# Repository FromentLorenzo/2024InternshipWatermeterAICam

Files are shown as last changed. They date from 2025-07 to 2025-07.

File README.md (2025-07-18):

# Project: Water Meter Reading with Camera-based Index Recognition

## Table of Contents

1. [Description of the Project](#1-description-of-the-project)
   - [Equipment Used](#equipment-used)
   - [Software Used](#software-used)
2. [What is Done](#2-what-is-done)
   - [ESP32-CAM Code](#about-the-esp32-cam-code)
   - [Convolutional Neural Network](#about-the-cnn)
   - [Camera Support](#about-the-support-for-the-esp32-cam)
   - [Grafana](#about-the-grafana)
3. [How to Use/Launch the Project](#3-how-to-uselaunch-the-project)
   - [Arduino Code](#arduino-code)
   - [Convolutional Neural Network Code](#convolutional-neural-network-code)
   - [Docker Container](#docker-container)
4. [What is Missing (Bugs)](#4-what-is-missing-bugs)

##
# 1. Description of the project:

The aim of this project was to enable automatic reading of water meter readings, enabling monitoring and automatic triggering of alerts in the event of abnormal consumption. 

## Equipment used
For this project, we used an ESP32-CAM  


## Software used

In order to code on the ESP32-CAM we used the software called Arduino IDE

 
We also used Google collab in order to train a CNN model able to predict digits.


# 2. What is done
## About the ESP32-CAM code

We developped a code able to take a picture with the flash LED of the ESP32-CAM, save it on the micro SD card, crop the original picture into 5 pictures (the 5 digits of the water meter) and save them on the micro SD. 

Then, we take these 5 pictures and apply the necessary preprocessing on them.

## About the CNN

We built our own dataset composed of digital digits but also half-half digits to solve the water meter display problem.
You can have access to the dataset in the ZIP file called "digits"

alt text for screen readers digit 1 from dataset
alt text for screen readers digit 1 merged from dataset

In our notebook "CNN_MODEL" you will find the differents step to train the model with comments.
Here are the main steps:
- Import necessary libraries
- Load the dataset
- Apply a full preprocessing to each pictures of the dataset
- Build a model with complex layers
- Train this model with the datasets' pictures
- Converting a Keras Model to a C++ Representation

With our dataset, preprocessing and model we are able to reach a 99% of accuracy. 

## About the support for the ESP32-CAM

We created a sort of support in order to protect the camera and make it motionless.

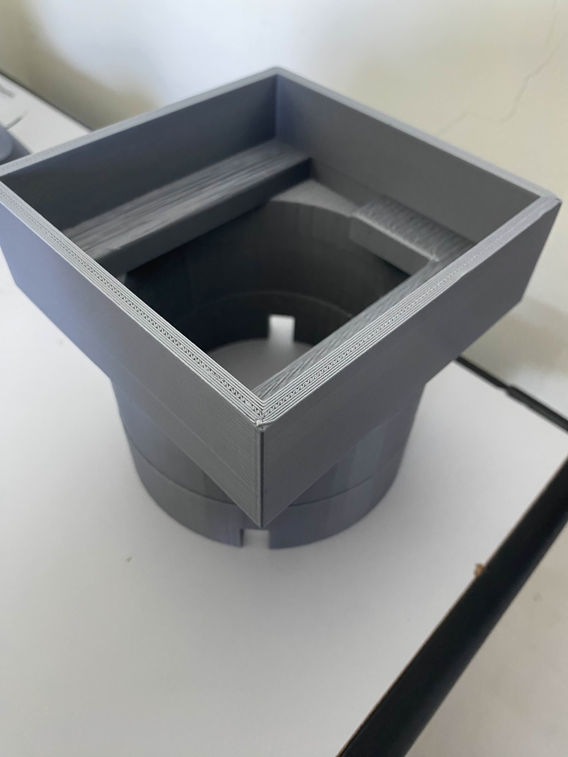
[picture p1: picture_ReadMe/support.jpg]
alt text for screen readers support for the camera


This support is made of 3 pieces in order to make it adjustable to have a better focus.

## About the Grafana

We developped a docker compose file composed of 3 services:
- Node-red, present for facilitate the connection between the LoRaWAN server and the database where values are stored 

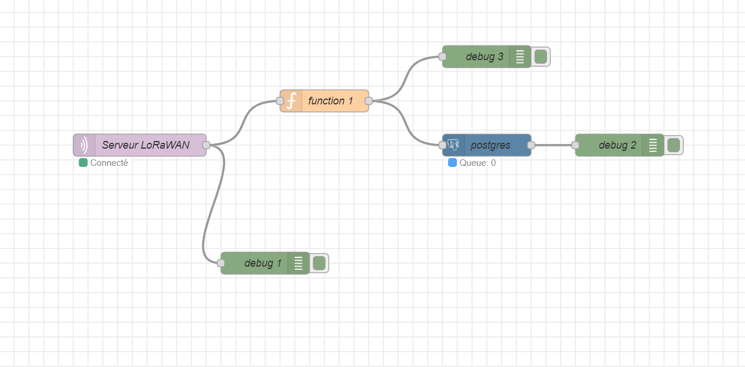
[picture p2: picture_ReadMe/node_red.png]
alt text for screen readers node-red page


- Postgres, which is the database used to store the values predicted and send by our ESP32-CAM
- Grafana, which is the service charged to get the values from the database and display them in order to keep track of consumption.

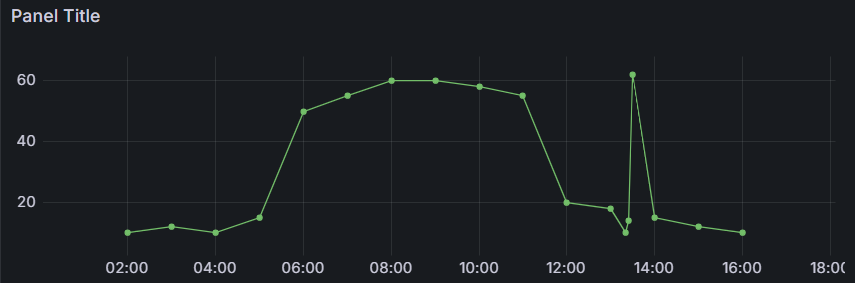
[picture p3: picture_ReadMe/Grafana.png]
alt text for screen readers Grafana page


# 3. How to use/launch the project

## Arduino code

First, lets set up the arduino IDE if you never used a ESP32-CAM.

Follow this tutorial to set up the Arduino IDE.
https://randomnerdtutorials.com/installing-esp32-arduino-ide-2-0/

After that, you can follow this tutorial to test if everything is working.
https://randomnerdtutorials.com/esp32-cam-video-streaming-face-recognition-arduino-ide/

After doing that, you can download the .ino file from the github project. Upload the code on the ESP32-CAM and open the Serial Monitor.
Here you will get an IP adress 

alt text for screen readers ip adress
Please visit this address in your browser and use the "Capture Image" button. This interface is provisional, designed to let you view the images captured by the ESP32-CAM without needing to remove the microSD card and connect it to your computer each time.
On this page, you can view the captured image along with the five preprocessed cropped images.

## Convolutional Neural Network code

If you want to take a look at the CNN code, you can download it from the github project. It is full of comments to help you understand how it is working. You also have to download the digits folder which is the dataset needed by the code to be able to train the model.
You can also use it to test the prediction on any pictures. (cell commented **"Manual Testing of the CNN Model"**)
The model has between 98 and 99% of accuracy and can easily predict digits even with average quality pictures.

## Docker container

In the github project, you can download the docker-compose file which is needed to launch the node-red, postgresSQL and grafana images.
Once downloaded, you have to type in a terminal the command: 
```
docker compose up -d --build
```

Once everything is launched, you can acces the node-red page at this adress: http://localhost:1880
You can access the Grafana page at this address:
http://localhost:3000/

The username/password are "**admin**"

# 4. What is missing (bugs)

In this project, some parts are missing in order to finish it.

1. **(BUG)** When we take a photo with the interface on the web server, the photo is correctly displayed wwith the cropped pictures. However, the pictures saved on the microSD are ALWAYS the same.

Here is the picture I take with the CAM

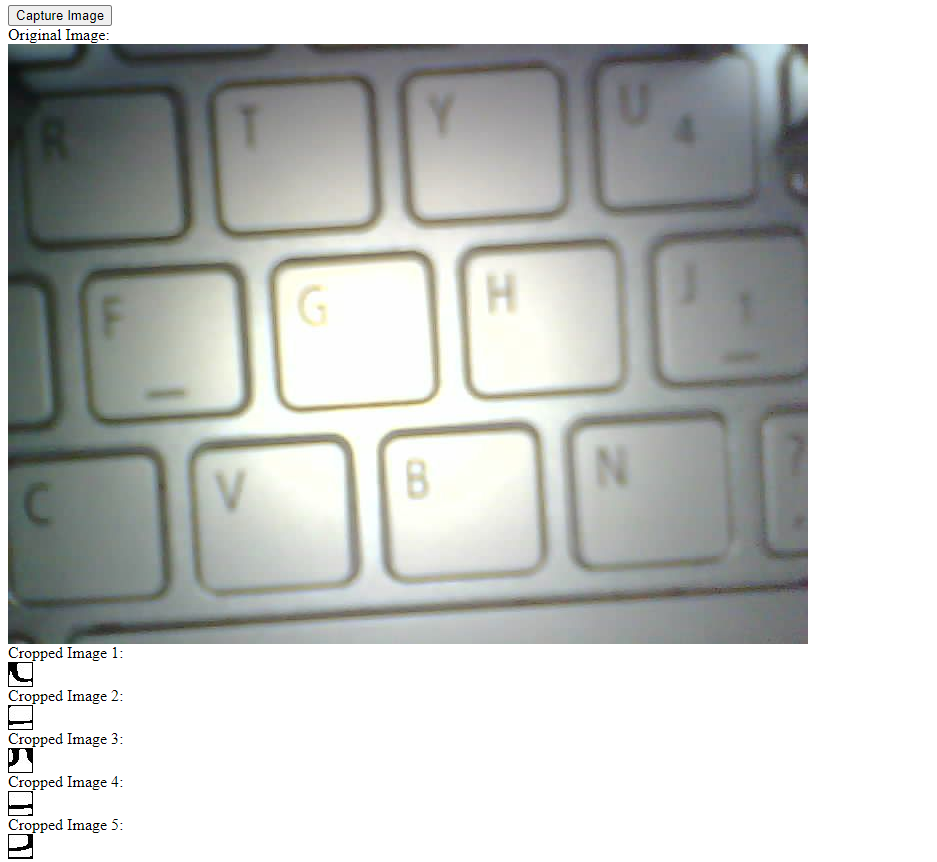
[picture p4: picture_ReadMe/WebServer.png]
alt text for screen readers WebServer pictures


Here is the picture saved on the microSD

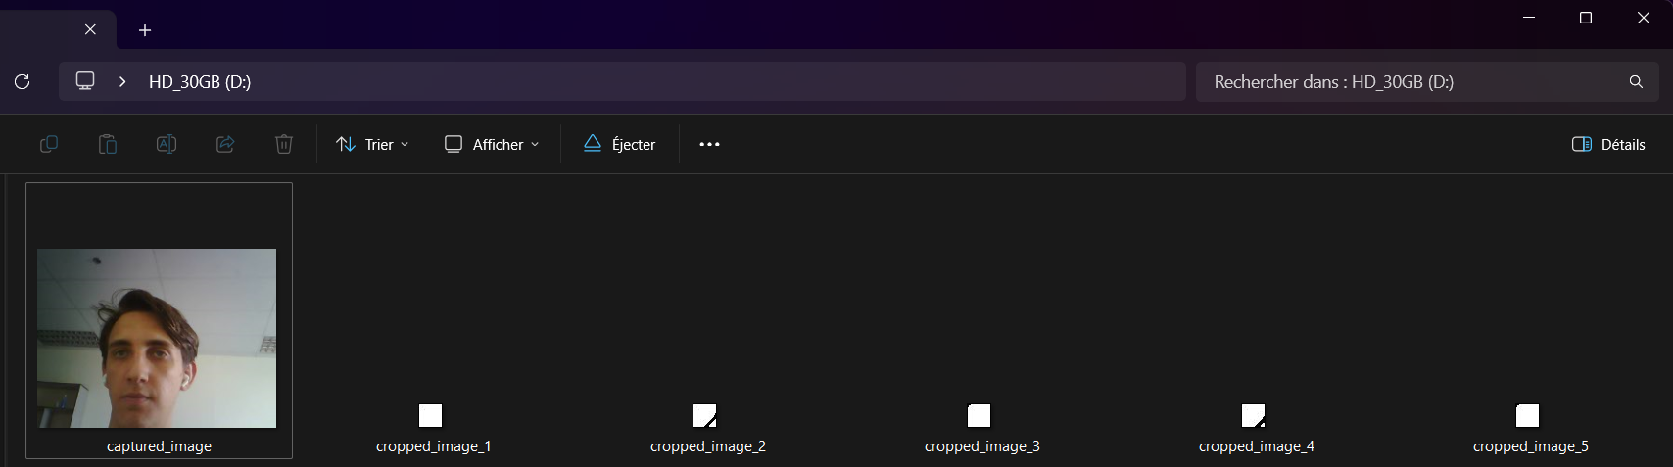
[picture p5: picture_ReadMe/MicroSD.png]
alt text for screen readers MicroSD pictures


I attempted to delete these pictures from the microSD, but they keep reappearing. I’ve formatted the microSD and cleared all memory allocations made in the Arduino code, yet the same pictures persist. They might be stored somewhere that I can’t locate.

2. **(Missing part)** Without the previous point, I was not able to test the CNN, so it is missing in the arduino code. He is converted in C code and uploaded on the github project. File named **"cnnFile.h"**.
3. **(Missing part)** Last part is the LoRaWAN part. It is needed to code the data transmission to LoRaWAN gateway.
4. **(Potential problem)** You may have a problem with the prediction because the pictures that the ESP32-CAM take have a really bad quality in my opinion. Even a human struggle to predict the value on the picture.

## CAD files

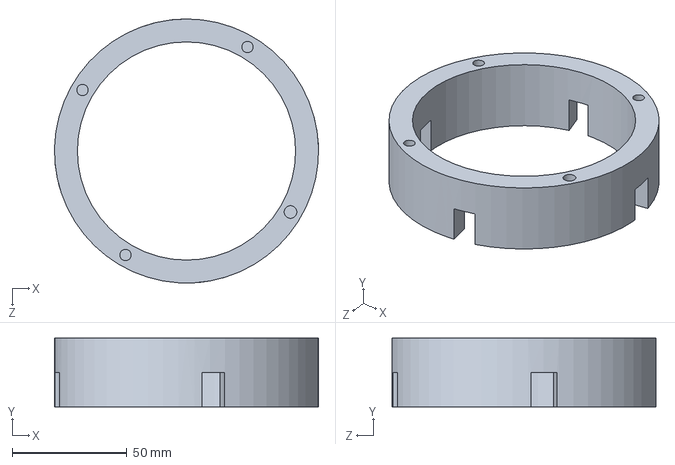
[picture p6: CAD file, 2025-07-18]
3D_Model_pieces/bottomV1.SLDPRT
114.9 x 30.0 x 115.0 mm

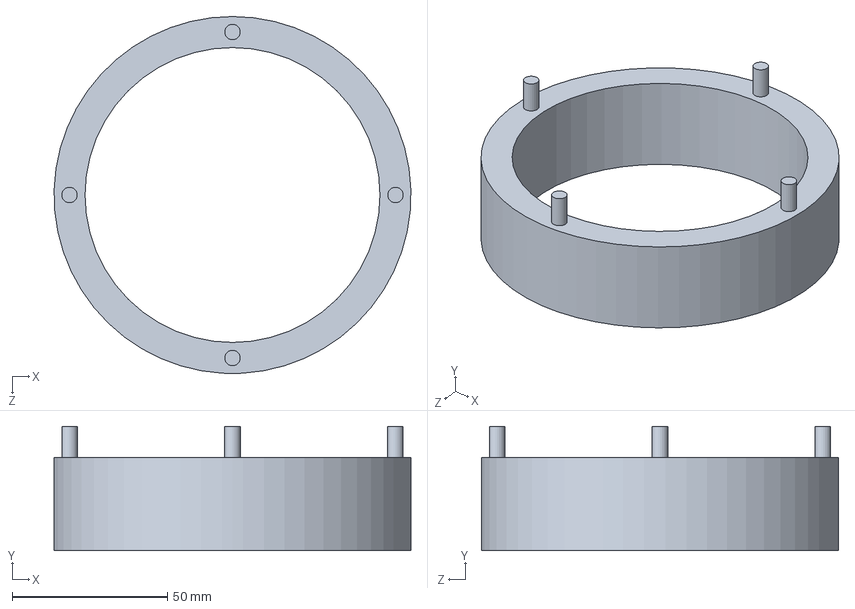
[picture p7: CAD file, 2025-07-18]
3D_Model_pieces/PièceDeBaseSupport.SLDPRT
114.9 x 40.0 x 115.0 mm

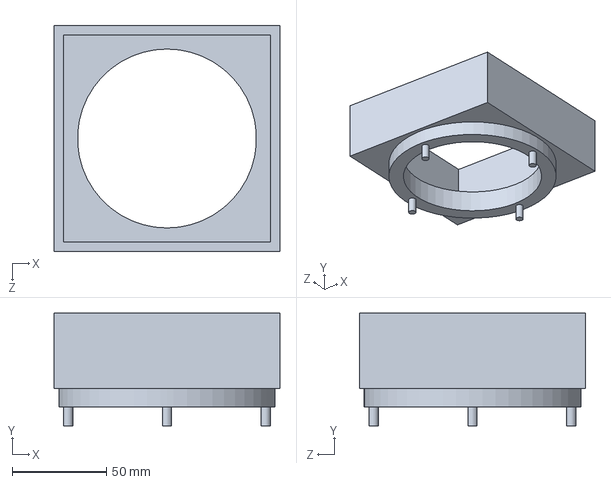
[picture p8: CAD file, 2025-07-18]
3D_Model_pieces/topV1.SLDPRT
120.0 x 60.0 x 120.0 mm

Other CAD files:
3D_Model_pieces/PièceDeBaseSupport.STL
3D_Model_pieces/bottomV1.STL
3D_Model_pieces/topV1.STL

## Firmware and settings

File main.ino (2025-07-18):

#include "esp_camera.h"
#include <WiFi.h>
#include <WebServer.h>
#include "Arduino.h"
#include "FS.h"
#include "SD_MMC.h"
#include "esp32-hal-ledc.h"

// Wi-Fi credentials
const char* ssid = "Khu S";
const char* password = "khu@s2022";

// Define GPIO pin numbers for the AI-THINKER camera module
#define CAMERA_MODEL_AI_THINKER // Has PSRAM
#define PWDN_GPIO_NUM     32
#define RESET_GPIO_NUM    -1
#define XCLK_GPIO_NUM      0
#define SIOD_GPIO_NUM     26
#define SIOC_GPIO_NUM     27
#define Y9_GPIO_NUM       35
#define Y8_GPIO_NUM       34
#define Y7_GPIO_NUM       39
#define Y6_GPIO_NUM       36
#define Y5_GPIO_NUM       21
#define Y4_GPIO_NUM       19
#define Y3_GPIO_NUM       18
#define Y2_GPIO_NUM        5
#define VSYNC_GPIO_NUM    25
#define HREF_GPIO_NUM     23
#define PCLK_GPIO_NUM     22
#define LED_GPIO_NUM       4
#define LED_LEDC_CHANNEL 2


WebServer server(80);

// Define cropping coordinates for five different regions of interest
// Each region is defined by its minimum and maximum x and y coordinates
int crop1_x_min = 195, crop1_y_min = 138, crop1_x_max = 255, crop1_y_max = 212;
int crop2_x_min = 273, crop2_y_min = 134, crop2_x_max = 331, crop2_y_max = 212;
int crop3_x_min = 353, crop3_y_min = 133, crop3_x_max = 408, crop3_y_max = 208;
int crop4_x_min = 432, crop4_y_min = 130, crop4_x_max = 487, crop4_y_max = 206;
int crop5_x_min = 513, crop5_y_min = 128, crop5_x_max = 565, crop5_y_max = 204;

// HTML response message to indicate successful image capture
String htmlBuffer = "<html><body><h1>Capture Successful!</h1></body></html>";


void handleRoot() {
  // Send an HTTP response to the client with a simple HTML page
  server.send(200, "text/html", 
              "<button id=\"captureBtn\">Capture Image</button>" // Button to trigger image capture
              "<div id=\"imageContainer\"></div>" // Container to display images
              "<div id=\"clickCoordinates\"></div>" // Container to display click coordinates
              "<script>"
              "document.getElementById('captureBtn').addEventListener('click', function() {" // Add click event listener to the button
              "  var xhr = new XMLHttpRequest();" // Create a new XMLHttpRequest object
              "  xhr.open('POST', '/capture', true);" // Configure it to send a POST request to the '/capture' endpoint
              "  xhr.onreadystatechange = function() {" // Function to handle changes in request state
              "    if (xhr.readyState == 4 && xhr.status == 200) {" // Check if the request is complete and successful
              "      var timestamp = new Date().getTime();" // Generate a timestamp to prevent image caching
              "      var originalImage = '<div>Original Image:<br><img id=\"capturedImage\" src=\"/captured_image.jpg?time=' + timestamp + '\" /></div>';" // HTML for displaying the original captured image
              "      var croppedImages = '';" // Variable to hold HTML for displaying cropped images
              "      for (var i = 1; i <= 5; i++) {" // Loop to generate HTML for each cropped image
              "        croppedImages += '<div>Cropped Image ' + i + ':<br><img src=\"/cropped_image_' + i + '.jpg?time=' + timestamp + '\" /></div>';" // Add HTML for each cropped image
              "      }"
              "      document.getElementById('imageContainer').innerHTML = originalImage + croppedImages;" // Update the image container with the new images
              "      document.getElementById('capturedImage').addEventListener('click', function(e) {" // Add click event listener to the original image
              "        var rect = e.target.getBoundingClientRect();" // Get the position of the image on the screen
              "        var x = e.clientX - rect.left;" // Calculate the x-coordinate of the click
              "        var y = e.clientY - rect.top;" // Calculate the y-coordinate of the click
              "        document.getElementById('clickCoordinates').innerHTML = 'Clicked at: (' + x + ', ' + y + ')';" // Display the coordinates of the click
              "      });"
              "    }"
              "  };"
              "  xhr.send();" // Send the request
              "});"
              "</script>");
}



camera_fb_t* rotate_image_180(camera_fb_t* src_fb) {
    int width = src_fb->width;
    int height = src_fb->height;
    int len = src_fb->len;

    // Allocate memory for the rotated image
    camera_fb_t* rotated_fb = (camera_fb_t*)malloc(sizeof(camera_fb_t));
    if (!rotated_fb) {
        Serial.println("Failed to allocate memory for rotated image");
        return NULL;
    }

    rotated_fb->buf = (uint8_t*)malloc(len);
    if (!rotated_fb->buf) {
        Serial.println("Failed to allocate memory for rotated image buffer");
        free(rotated_fb);
        return NULL;
    }

    rotated_fb->format = src_fb->format;
    rotated_fb->width = width;
    rotated_fb->height = height;
    rotated_fb->len = len;

    // Perform the 180-degree rotation
    for (int y = 0; y < height; y++) {
        for (int x = 0; x < width; x++) {
            int src_index = (y * width + x) * 3;
            int rotated_index = ((height - y - 1) * width + (width - x - 1)) * 3;

            rotated_fb->buf[rotated_index] = src_fb->buf[src_index];
            rotated_fb->buf[rotated_index + 1] = src_fb->buf[src_index + 1];
            rotated_fb->buf[rotated_index + 2] = src_fb->buf[src_index + 2];
        }
    }

    return rotated_fb;
}


void convert_to_grayscale(uint8_t* src, uint8_t* dest, int width, int height) {
    // Iterate through each pixel in the image
    for (int i = 0; i < height; i++) {
        for (int j = 0; j < width; j++) {
            // Calculate the index for the current pixel in the source buffer
            int index = (i * width + j) * 3;

            // Extract the RGB components from the source image
            uint8_t r = src[index];     // Red component
            uint8_t g = src[index + 1]; // Green component
            uint8_t b = src[index + 2]; // Blue component

            // Calculate the grayscale value using standard luminance formula
            // The weights 299, 587, and 114 approximate human perception of color brightness
            uint8_t gray = (r * 299 + g * 587 + b * 114) / 1000;

            // Store the grayscale value in the destination buffer
            dest[i * width + j] = gray;
        }
    }
}


void normalize_image(uint8_t* src, float* dest, int width, int height) {
    // Iterate through each pixel in the image
    for (int i = 0; i < width * height; i++) {
        // Normalize pixel value from 0-255 range to 0.0-1.0 range
        dest[i] = src[i] / 255.0f;
    }
}


void createGaussianKernel(float kernel[5][5], float sigma) {
    int size = 5; // Kernel size is 5x5
    float sum = 0.0f; // To store the sum of all elements for normalization
    int halfSize = size / 2; // Half the size of the kernel
    float twoSigmaSquare = 2.0f * sigma * sigma; // Precompute the value for efficiency

    // Loop through each element in the 5x5 kernel
    for (int y = -halfSize; y <= halfSize; y++) {
        for (int x = -halfSize; x <= halfSize; x++) {
            // Calculate the exponent for the Gaussian function
            float exponent = -((x * x + y * y) / twoSigmaSquare);
            // Calculate the kernel value using the Gaussian formula
            kernel[y + halfSize][x + halfSize] = exp(exponent) / (M_PI * twoSigmaSquare);
            // Sum up all kernel values for normalization
            sum += kernel[y + halfSize][x + halfSize];
        }
    }

    // Normalize the kernel so that the sum of all its elements equals 1
    for (int y = 0; y < size; y++) {
        for (int x = 0; x < size; x++) {
            kernel[y][x] /= sum;
        }
    }
}


void applyGaussianBlur(uint8_t* src, uint8_t* dest, int width, int height, float sigma) {
    float kernel[5][5]; // Array to store the Gaussian kernel
    createGaussianKernel(kernel, sigma); // Create the Gaussian kernel based on sigma

    int halfSize = 2; // Half the size of the 5x5 kernel, which is 2
    for (int y = 0; y < height; y++) {
        for (int x = 0; x < width; x++) {
            float sum = 0.0f; // To accumulate the weighted sum of pixels
            float norm = 0.0f; // To accumulate the normalization factor (not used here)

            // Apply the kernel to the current pixel
            for (int ky = -halfSize; ky <= halfSize; ky++) {
                for (int kx = -halfSize; kx <= halfSize; kx++) {
                    int iy = y + ky; // Y coordinate of the pixel in the kernel
                    int ix = x + kx; // X coordinate of the pixel in the kernel

                    // Check if the kernel pixel is within image bounds
                    if (ix >= 0 && ix < width && iy >= 0 && iy < height) {
                        // Accumulate the weighted sum of pixels
                        sum += src[iy * width + ix] * kernel[ky + halfSize][kx + halfSize];
                        norm += kernel[ky + halfSize][kx + halfSize]; // Accumulate the normalization factor
                    }
                }
            }
            // Set the blurred pixel value
            dest[y * width + x] = (uint8_t)sum;
        }
    }
}



void binarize_image(uint8_t* src, uint8_t* dest, int width, int height) {
    // Find the Otsu threshold
    int hist[256] = {0}; // Histogram array to count pixel occurrences for each grayscale level
    for (int i = 0; i < width * height; i++) {
        hist[src[i]]++; // Populate the histogram with pixel values
    }

    int total = width * height; // Total number of pixels in the image
    float sum = 0; // Sum of all pixel values multiplied by their occurrence
    for (int i = 0; i < 256; i++) {
        sum += i * hist[i]; // Calculate the weighted sum of pixel values
    }

    float sumB = 0; // Weighted sum of background pixel values
    float wB = 0; // Weight of background pixels
    float wF = 0; // Weight of foreground pixels
    float varMax = 0; // Maximum between-class variance
    float threshold = 0; // Otsu threshold

    for (int t = 0; t < 256; t++) {
        wB += hist[t]; // Update weight of background pixels
        if (wB == 0) continue; // Skip if background weight is zero

        wF = total - wB; // Weight of foreground pixels
        if (wF == 0) break; // Break if foreground weight is zero

        sumB += (float)(t * hist[t]); // Update weighted sum of background pixel values

        float mB = sumB / wB; // Mean of background pixels
        float mF = (sum - sumB) / wF; // Mean of foreground pixels

        float varBetween = wB * wF * (mB - mF) * (mB - mF); // Between-class variance

        if (varBetween > varMax) {
            varMax = varBetween; // Update maximum variance
            threshold = t; // Update threshold
        }
    }

    // Binarize the image using the Otsu threshold
    for (int i = 0; i < width * height; i++) {
        dest[i] = (src[i] > threshold) ? 255 : 0; // Apply the threshold to binarize the image
    }
}



// Function to resize an image using nearest neighbor interpolation
void resizeImage(uint8_t* src, uint8_t* dest, int srcWidth, int srcHeight, int destWidth, int destHeight) {
    float xRatio = static_cast<float>(srcWidth) / destWidth; // Calculate the ratio for width scaling
    float yRatio = static_cast<float>(srcHeight) / destHeight; // Calculate the ratio for height scaling
    float px, py; // Coordinates in the source image
    int x, y; // Integer coordinates in the source image

    for (int i = 0; i < destHeight; i++) { // Loop through each row of the destination image
        for (int j = 0; j < destWidth; j++) { // Loop through each column of the destination image
            px = j * xRatio; // Calculate the x-coordinate in the source image
            py = i * yRatio; // Calculate the y-coordinate in the source image
            x = static_cast<int>(px); // Convert floating-point coordinates to integer
            y = static_cast<int>(py); // Convert floating-point coordinates to integer

            int srcIndex = (y * srcWidth + x) * 3; // Calculate index in the source image
            int destIndex = (i * destWidth + j) * 3; // Calculate index in the destination image

            // Copy pixel values from the source image to the destination image
            dest[destIndex] = src[srcIndex];
            dest[destIndex + 1] = src[srcIndex + 1];
            dest[destIndex + 2] = src[srcIndex + 2];
        }
    }
}



camera_fb_t* crop_image(camera_fb_t* src_fb, int x_min, int y_min, int x_max, int y_max) {
    int src_width = src_fb->width; // Width of the source image
    int src_height = src_fb->height; // Height of the source image

    // Ensure crop coordinates are within the bounds of the source image
    if (x_min < 0) x_min = 0;
    if (y_min < 0) y_min = 0;
    if (x_max > src_width) x_max = src_width;
    if (y_max > src_height) y_max = src_height;

    int crop_width = x_max - x_min; // Width of the cropped image
    int crop_height = y_max - y_min; // Height of the cropped image

    // Allocate memory for the cropped image
    camera_fb_t* cropped_fb = (camera_fb_t*)malloc(sizeof(camera_fb_t));
    if (!cropped_fb) {
        Serial.println("Failed to allocate memory for cropped image");
        return NULL;
    }

    cropped_fb->format = PIXFORMAT_RGB888; // Set the image format to RGB888
    cropped_fb->width = crop_width; // Set the width of the cropped image
    cropped_fb->height = crop_height; // Set the height of the cropped image
    cropped_fb->len = crop_width * crop_height * 3; // Calculate the length of the cropped image buffer
    cropped_fb->buf = (uint8_t*)malloc(cropped_fb->len); // Allocate memory for the cropped image buffer

    if (!cropped_fb->buf) {
        Serial.println("Failed to allocate memory for cropped image buffer");
        free(cropped_fb); // Free previously allocated memory
        return NULL;
    }

    // Copy pixel values from the source image to the cropped image
    for (int y = 0; y < crop_height; y++) {
        for (int x = 0; x < crop_width; x++) {
            int src_index = ((y + y_min) * src_width + (x + x_min)) * 3; // Calculate index in the source image
            int cropped_index = (y * crop_width + x) * 3; // Calculate index in the cropped image
            cropped_fb->buf[cropped_index] = src_fb->buf[src_index];
            cropped_fb->buf[cropped_index + 1] = src_fb->buf[src_index + 1];
            cropped_fb->buf[cropped_index + 2] = src_fb->buf[src_index + 2];
        }
    }

    return cropped_fb; // Return the cropped image
}



// Function to convert a JPEG image to RGB format
camera_fb_t* convert_jpeg_to_rgb(camera_fb_t* fb) {
    // Allocate memory for the RGB image buffer
    uint8_t* rgb_buf = (uint8_t*)malloc(fb->width * fb->height * 3);
    if (!rgb_buf) {
        Serial.println("Memory allocation failed for RGB image");
        return NULL;
    }

    // Convert JPEG image to RGB format
    if (!fmt2rgb888(fb->buf, fb->len, PIXFORMAT_JPEG, rgb_buf)) {
        Serial.println("JPEG to RGB conversion failed");
        free(rgb_buf); // Free the allocated memory if conversion fails
        return NULL;
    }

    // Allocate memory for the camera framebuffer structure
    camera_fb_t* rgb_fb = (camera_fb_t*)malloc(sizeof(camera_fb_t));
    if (!rgb_fb) {
        Serial.println("Memory allocation failed for camera framebuffer");
        free(rgb_buf); // Free the allocated memory if framebuffer allocation fails
        return NULL;
    }

    // Set up the framebuffer with RGB image data
    rgb_fb->buf = rgb_buf; // Pointer to the RGB image buffer
    rgb_fb->len = fb->width * fb->height * 3; // Length of the RGB image buffer
    rgb_fb->width = fb->width; // Width of the image
    rgb_fb->height = fb->height; // Height of the image
    rgb_fb->format = PIXFORMAT_RGB888; // Set the format to RGB888

    return rgb_fb; // Return the framebuffer containing the RGB image
}



// Function to enable or disable the LED with a specific intensity
void enable_led(bool en)
{
    uint8_t intensity = 4; // Set the LED intensity level

    // Check if the LED should be enabled
    if (en) {
        ledcWrite(LED_LEDC_CHANNEL, intensity); // Set the LED intensity
    } else {
        ledcWrite(LED_LEDC_CHANNEL, 0); // Turn off the LED
    }

    // Print the LED intensity to the serial monitor
    Serial.println("Set LED intensity to");
    Serial.println(intensity);
}




// Function to handle the image capture process
void handleCapture() {
    Serial.println("Capture request received"); // Log the capture request
    enable_led(true); // Turn on the LED to indicate capture process
    vTaskDelay(150 / portTICK_PERIOD_MS); // Delay to allow LED to turn on

    // Capture the image from the camera
    camera_fb_t* fb = esp_camera_fb_get();
    enable_led(false); // Turn off the LED after capture
    if (!fb) {
        Serial.println("Camera capture failed"); // Log failure
        server.send(500, "text/plain", "Camera capture failed"); // Send error response
        return;
    }

    Serial.println("Camera capture successful"); // Log success

    // Convert the captured JPEG image to RGB format for further processing
    camera_fb_t* rgb_fb = convert_jpeg_to_rgb(fb);
    if (!rgb_fb) {
        Serial.println("JPEG to RGB conversion failed"); // Log failure
        server.send(500, "text/plain", "JPEG to RGB conversion failed"); // Send error response
        esp_camera_fb_return(fb); // Return the frame buffer to free memory
        return;
    }

    // Rotate the RGB image by 180 degrees
    camera_fb_t* rotated_fb = rotate_image_180(rgb_fb);
    if (!rotated_fb) {
        Serial.println("Image rotation failed"); // Log failure
        server.send(500, "text/plain", "Image rotation failed"); // Send error response
        free(rgb_fb->buf); // Free memory
        free(rgb_fb); // Free memory
        esp_camera_fb_return(fb); // Return the frame buffer to free memory
        return;
    }

    // Save the rotated image to the SD card
    String path = "/captured_image.jpg";
    fs::FS &fs = SD_MMC;
    File file = fs.open(path.c_str(), FILE_WRITE);
    if (!file) {
        Serial.println("Failed to open file for writing"); // Log failure
        server.send(500, "text/plain", "Failed to open file for writing"); // Send error response
        free(rotated_fb->buf); // Free memory
        free(rotated_fb); // Free memory
        esp_camera_fb_return(fb); // Return the frame buffer to free memory
        return;
    }

    size_t jpeg_buf_len = 0;
    uint8_t *jpeg_buf = NULL;
    if (fmt2jpg(rotated_fb->buf, rotated_fb->len, rotated_fb->width, rotated_fb->height, PIXFORMAT_RGB888, 80, &jpeg_buf, &jpeg_buf_len)) {
        file.write(jpeg_buf, jpeg_buf_len); // Write the JPEG image to file
        free(jpeg_buf); // Free memory
    }
    file.close(); // Close the file
    Serial.println("Image saved to SD card"); // Log success

    // Crop and save each region of interest
    camera_fb_t* cropped_fb1 = crop_image(rotated_fb, crop1_x_min, crop1_y_min, crop1_x_max, crop1_y_max);
    saveCroppedImage(cropped_fb1, "/cropped_image_1.jpg");

    camera_fb_t* cropped_fb2 = crop_image(rotated_fb, crop2_x_min, crop2_y_min, crop2_x_max, crop2_y_max);
    saveCroppedImage(cropped_fb2, "/cropped_image_2.jpg");

    camera_fb_t* cropped_fb3 = crop_image(rotated_fb, crop3_x_min, crop3_y_min, crop3_x_max, crop3_y_max);
    saveCroppedImage(cropped_fb3, "/cropped_image_3.jpg");

    camera_fb_t* cropped_fb4 = crop_image(rotated_fb, crop4_x_min, crop4_y_min, crop4_x_max, crop4_y_max);
    saveCroppedImage(cropped_fb4, "/cropped_image_4.jpg");

    // Add the 5th cropped image
    camera_fb_t* cropped_fb5 = crop_image(rotated_fb, crop5_x_min, crop5_y_min, crop5_x_max, crop5_y_max);
    saveCroppedImage(cropped_fb5, "/cropped_image_5.jpg");

    // Free memory allocated for the images
    free(rotated_fb->buf); // Free memory of the rotated image
    free(rotated_fb); // Free memory of the rotated image structure
    free(rgb_fb->buf); // Free memory of the RGB image
    free(rgb_fb); // Free memory of the RGB image structure

    // Return the camera frame buffer to free memory
    esp_camera_fb_return(fb);

    // Send an HTML response to the client
    server.send(200, "text/html", htmlBuffer); // Send success response
    Serial.println("HTML response sent"); // Log response sent
}
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
void loop() {
  server.handleClient();
}
